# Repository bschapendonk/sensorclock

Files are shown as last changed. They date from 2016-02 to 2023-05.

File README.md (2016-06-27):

# sensorclock
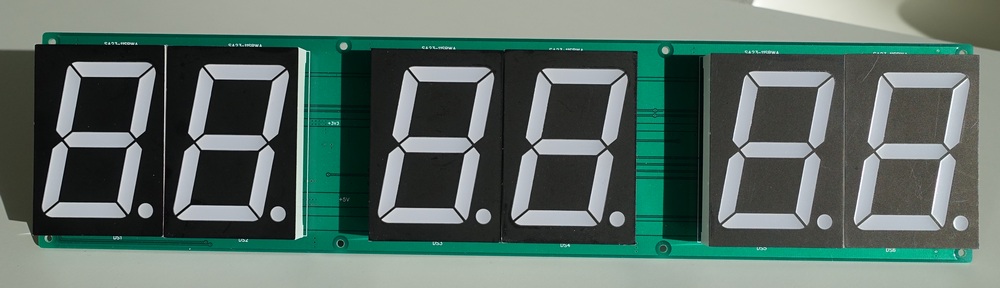
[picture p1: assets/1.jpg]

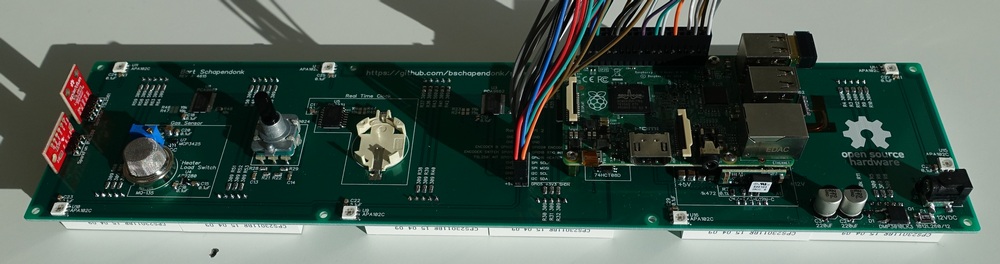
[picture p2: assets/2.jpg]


I'm a software engineer by trade and I was looking for a nice project to use [Windows 10 IoT Core](https://dev.windows.com/en-us/iot) running on a Raspberry Pi 2 Model B.
So I decided on an clock inspired by Steve Gardner's [6 Digit LED Clock](http://sdgelectronics.co.uk/ledclock-projects/) project.
Initially I only planned on the clock, but I ended up addeding a bunch of sensors that might be used for some "IoT" in the feature.

Everything is controlled thru I2C, except the RGB leds which use SPI, some GPIO's for the rotary encoder, interrupts from the sensors and control lines to turn off the +3V3 (to reset all I2C devices). Basically any MCU that has I2C, SPI and some GPIO's can be used.

*The new Raspberry Pi 3 is pin compatible and runs even better*

* [Schematic](/hardware/pdf/sensorclock.pdf)
* [Board Top](/hardware/pdf/sensorclock_top.pdf)
* [Board Bottom](/hardware/pdf/sensorclock_bottom.pdf)
* [Gerbers](/hardware/gerber)

## things learned / improvements / mistakes
* U2 has an invalid I2C address
 * [Workaround] Use ALLCALL to enable SUBADDR1 on all PCA9622's, then disable SUBADDR1 on the good addressed PCA9622's and use SUBADDR1 to address the wrong addressed U2
* The MCP3425 and DS3231 have the same I2C address #fail
 * [Workaround] For now I cut the SDA/SCL traces to the DS3231
* The interconnect between te sensorclock and the Raspberrry Pi 2
 * This is a custom cable which saved time in design process of the board (less complex routing), but in hindsight this was a mistake since the assembly of the cable is quite difficult and error prone.
 
## features
* Windows 10 IoT Core controlled
* Six 7-segment 70mm (2.3") high displays
* Eight APA102C serial controlled RGB led's for ambient lighting or mood indication
* Temperature, humidity, barometric pressure, ambient light and air quality sensors
* Mechanical rotary encoder with switch for user input

## components
* Raspberry Pi 2 Model B
* ~~DS3231 [http://datasheets.maximintegrated.com/en/ds/DS3231.pdf]~~ (address conflict)
* PEC16 [http://www.bourns.com/data/global/pdfs/pec16.pdf]
* APA102C [http://www.adafruit.com/datasheets/APA102.pdf]

### clock
* PCA9622 [http://www.nxp.com/documents/data_sheet/PCA9622.pdf]
* SA23-11SRWA [http://www.kingbrightusa.com/images/catalog/spec/SA23-11SRWA.pdf]

### sensors
* SparkFun Atmospheric Sensor Breakout - BME280 [https://www.sparkfun.com/products/13676]
* SparkFun Luminosity Sensor Breakout - TSL2561 [https://www.sparkfun.com/products/12055]
* MQ-135 air quality sensor, ADC and loadswitch
 * MCP3425 [http://ww1.microchip.com/downloads/en/DeviceDoc/22072b.pdf]
 * AP2280 [http://www.diodes.com/_files/datasheets/AP2280.pdf]

**!!This is a work in progress, use at your own risk!!**

## renders

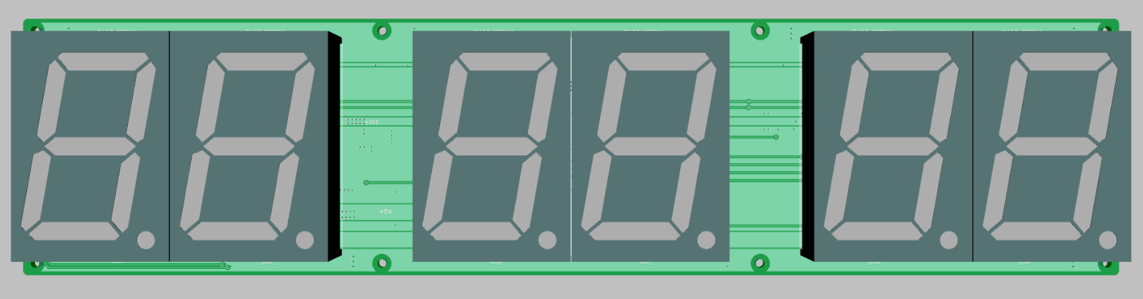
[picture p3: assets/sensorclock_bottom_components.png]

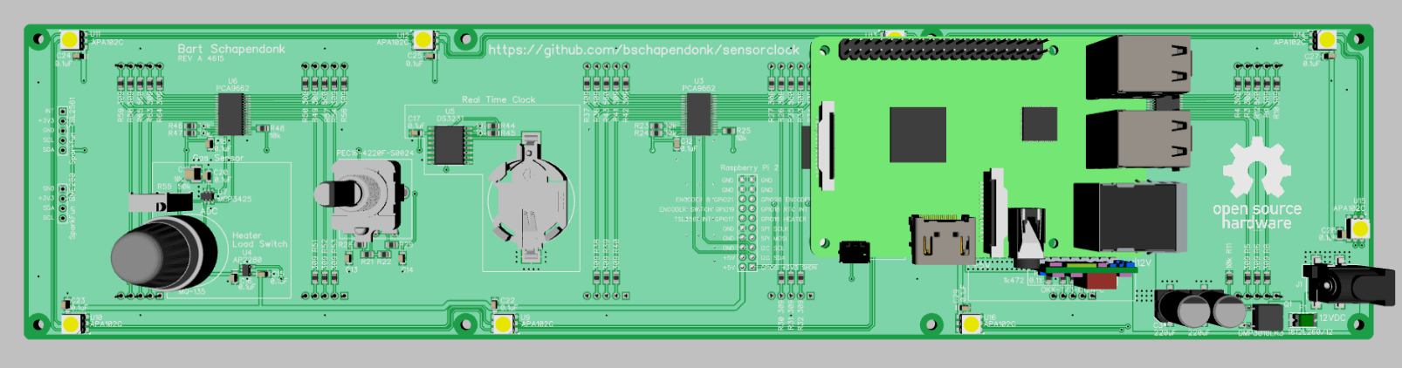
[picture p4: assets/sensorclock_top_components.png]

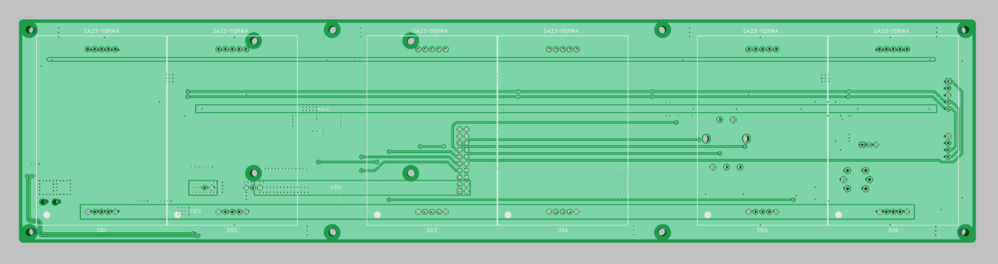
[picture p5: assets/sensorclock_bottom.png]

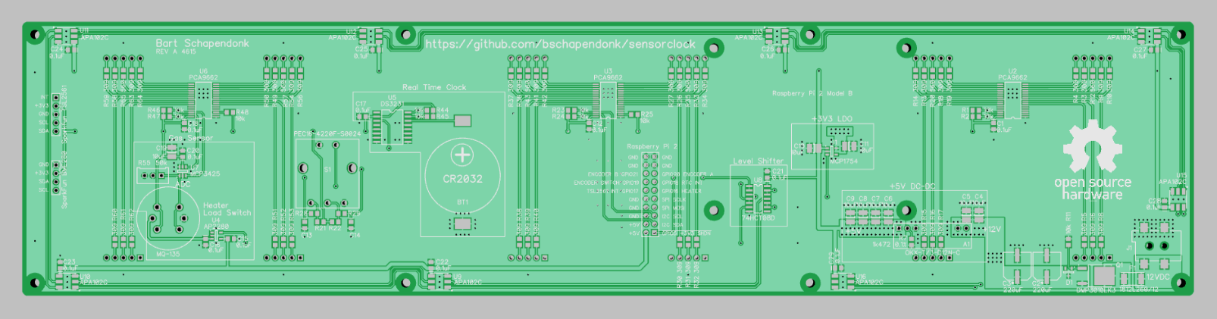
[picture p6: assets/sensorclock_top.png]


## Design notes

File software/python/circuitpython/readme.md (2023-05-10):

## CircuitPython Libraries
[CircuitPython Libraries
](https://circuitpython.org/libraries)

### Community Bundle
- adafruit_bme280/
- adafruit_bus_device/
- adafruit_register /
- asyncio/
- adafruit_datetime
- adafruit_ds3231
- adafruit_dotstar
- adafruit_ntp
- adafruit_ticks
- adafruit_tsl2561

### Community Bundle
- tzdb/

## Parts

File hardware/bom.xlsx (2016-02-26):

sensorclock_without_rtc_and_rotaryencoder
Mouser No | Mfr. # | Manufacturer | Desc. | RoHS | Lifecycle | Customer Part No. | Order Qty. | Price (EUR) | Ext: (EUR)
667-ERJ-6ENF1002V | ERJ-6ENF1002V | Panasonic | Thick Film Resistors - SMD 0805 10Kohms 1% Tol | RoHS Compliant By Exemption |  |  | 13 | € 0,024 | € 0,31
667-ERJ-6ENF3090V | ERJ-6ENF3090V | Panasonic | Thick Film Resistors - SMD 0805 309ohms 1% Tol | RoHS Compliant By Exemption |  |  | 42 | € 0,026 | € 1,09
667-ERJ-6ENF5600V | ERJ-6ENF5600V | Panasonic | Thick Film Resistors - SMD 0805 560ohms 1% Tol | RoHS Compliant By Exemption |  |  | 6 | € 0,091 | € 0,55
552-PSAC30U-120-R | PSAC30U-120-R | Phihong | Desktop AC Adapters 30W 12V 2.5A 3-WIRE INPUT ADAPTER | RoHS Compliant | End of Life |  | 1 | € 21,56 | € 21,56
771-74HCT08D-T | 74HCT08D,653 | NXP | Logic Gates QUAD 2-IN AND GATE | RoHS Compliant |  |  | 1 | € 0,398 | € 0,40
579-MCP3425A0T-E/CH | MCP3425A0T-E/CH | Microchip | Analog to Digital Converters - ADC 16-B delta-sigma ADC Sngl Ch 15sps | RoHS Compliant |  |  | 1 | € 2,15 | € 2,15
621-AP2280-1WG-7 | AP2280-1WG-7 | Diodes Incorporated | Power Switch ICs - Power Distribution Programmable Load Switch 1.5V - 6V | RoHS Compliant |  |  | 1 | € 0,585 | € 0,59
771-PCA9622DR,118 | PCA9622DR,118 | NXP | LED Lighting Drivers 16-BIT FM+ I2C-BUS 100mA 40V LED driver | RoHS Compliant |  |  | 3 | € 2,28 | € 6,84
579-MCP1754T3302EOT | MCP1754T-3302E/OT | Microchip | LDO Voltage Regulators LDO | RoHS Compliant |  |  | 1 | € 0,398 | € 0,40
652-3296W-1-503LF | 3296W-1-503LF | Bourns | Trimmer Resistors - Through Hole 3/8" 50Kohms Sealed Vertical Adjust | RoHS Compliant By Exemption |  |  | 1 | € 2,28 | € 2,28
667-ERA-6AEB1471V | ERA-6AEB1471V | Panasonic | Thin Film Resistors - SMD 0805 1.47Kohm 0.1% 25ppm | RoHS Compliant By Exemption |  |  | 1 | € 0,57 | € 0,57
621-DMP3010LK3-13 | DMP3010LK3-13 | Diodes Incorporated | MOSFET MOSFET BVDSS: 25V-30 V-30V TO252 T&R 2.5K | RoHS Compliant |  |  | 1 | € 0,604 | € 0,60
490-PJ-002AH-SMT-TR | PJ-002AH-SMT-TR | CUI Inc. | DC Power Connectors Power Jacks | RoHS Compliant | New At Mouser |  | 1 | € 1,56 | € 1,56
576-1812L260/12MR | 1812L260/12MR | Littelfuse | Resettable Fuses - PPTC PTC 12V POLY SURF MOUNT 1812 2.6A | RoHS Compliant |  |  | 1 | € 0,869 | € 0,87
604-SA23-11SRWA | SA23-11SRWA | Kingbright | LED Displays & Accessories SUPER RED DIFFUSED 1 DIGIT | RoHS Compliant |  |  | 6 | € 5,51 | € 33,06
863-MMBZ5250BLT1G | MMBZ5250BLT1G | ON Semiconductor | Zener Diodes 20V 225mW | RoHS Compliant |  |  | 1 | € 0,127 | € 0,13
81-GRM32DR71E106KA12 | GRM32DR71E106KA12L | Murata | Multilayer Ceramic Capacitors MLCC - SMD/SMT 1210 10uF 25volts X7R 10% | RoHS Compliant |  |  | 9 | € 0,661 | € 5,95
667-EEE-TG1E221UP | EEE-TG1E221UP | Panasonic | Aluminium Electrolytic Capacitors - SMD 220UF 25V ELECT TG SMD | RoHS Compliant |  |  | 2 | € 0,896 | € 1,79
81-GRM40X104K25L | GRM21BR71E104KA01L | Murata | Multilayer Ceramic Capacitors MLCC - SMD/SMT 0805 0.1uF 25volts X7R 10% | RoHS Compliant |  |  | 15 | € 0,068 | € 1,02
580-OKX-T/3-D12N-C | OKX-T/3-D12N-C | Murata | Non-Isolated DC/DC Converters 12Vin 0.75-5.5Vout 3A Neg logic SIP | RoHS Compliant |  |  | 1 | € 5,61 | € 5,61

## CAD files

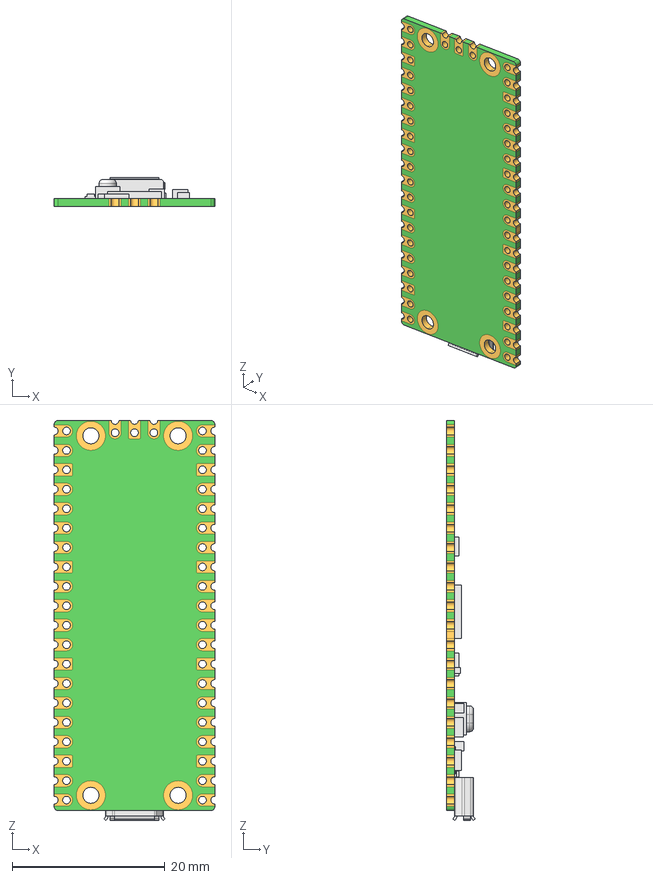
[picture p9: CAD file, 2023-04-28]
hardware/picow_adapter/3dmodels/Pico-R3-PICOPICO_assm_140121.step
21.0 x 3.73 x 52.3 mm
PICO_REF_BOARD.STEP
PICO_REF_USB.STEP
PICO_REF_USB.STEP001
PICO_REF_USB.STEP002
PICO_REF_USB.STEP003
PICO_REF_USB.STEP004
PICO_REF_SWITCH.STEP
PICO_REF_MICROCONTROLLER.STEP
PICO_REF_LED.STEP
PICO_REF_ONSEMI.STEP
PICO_BOURNS.STEP
PICO_MURATA.STEP x 2
PICO_RICHTEK.STEP
PICO_DIODES.STEP
PICO_AEL.STEP
PICO_WINBOND.STEP

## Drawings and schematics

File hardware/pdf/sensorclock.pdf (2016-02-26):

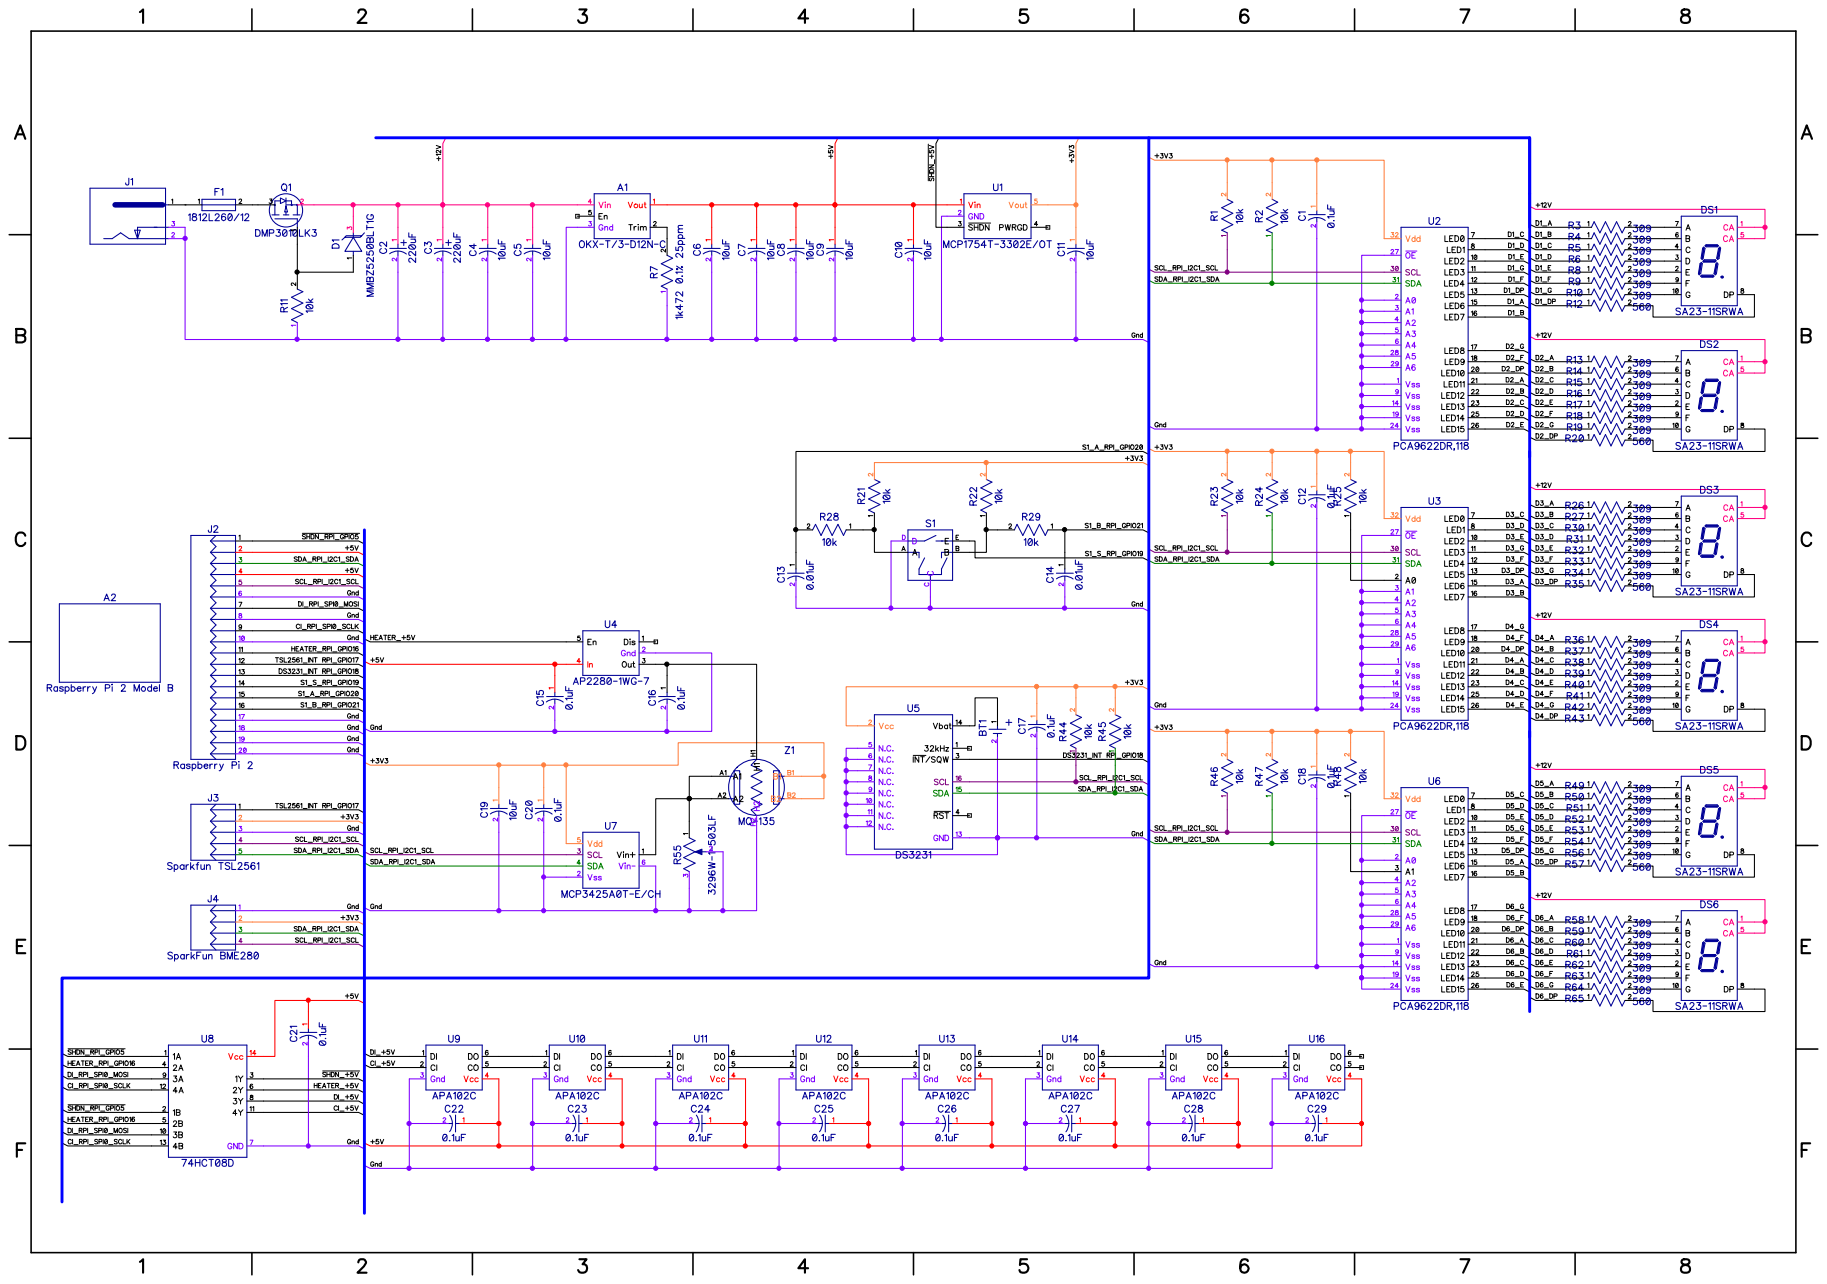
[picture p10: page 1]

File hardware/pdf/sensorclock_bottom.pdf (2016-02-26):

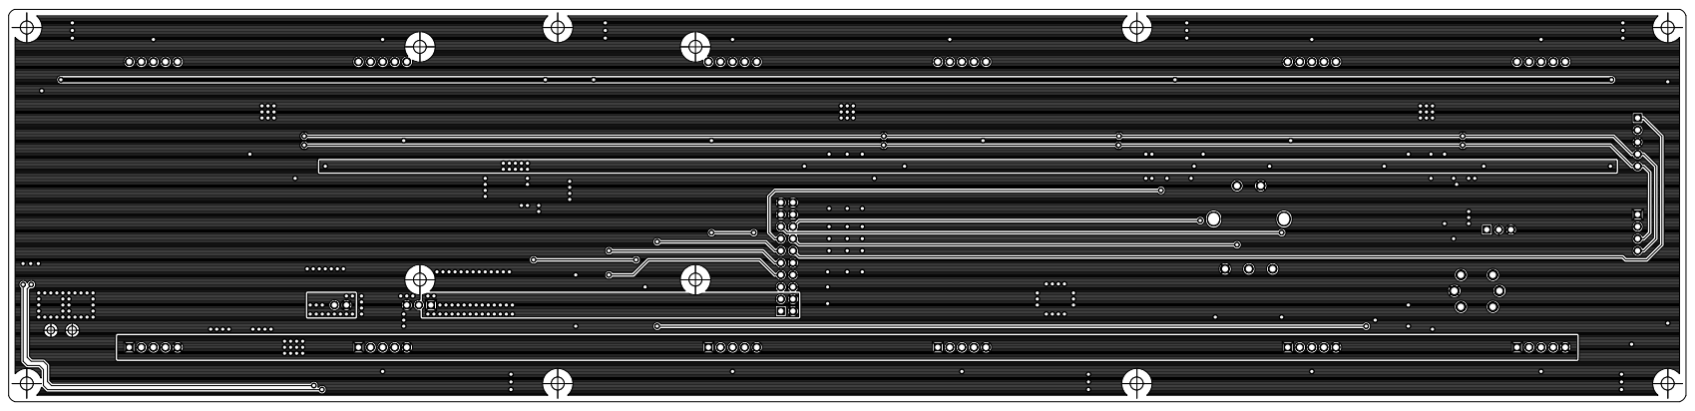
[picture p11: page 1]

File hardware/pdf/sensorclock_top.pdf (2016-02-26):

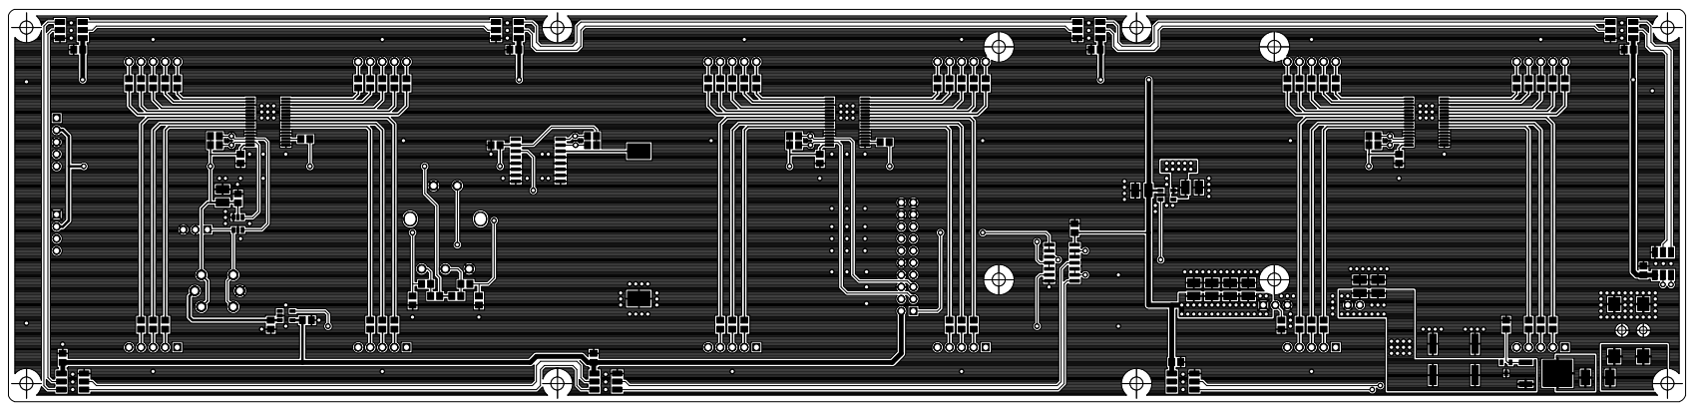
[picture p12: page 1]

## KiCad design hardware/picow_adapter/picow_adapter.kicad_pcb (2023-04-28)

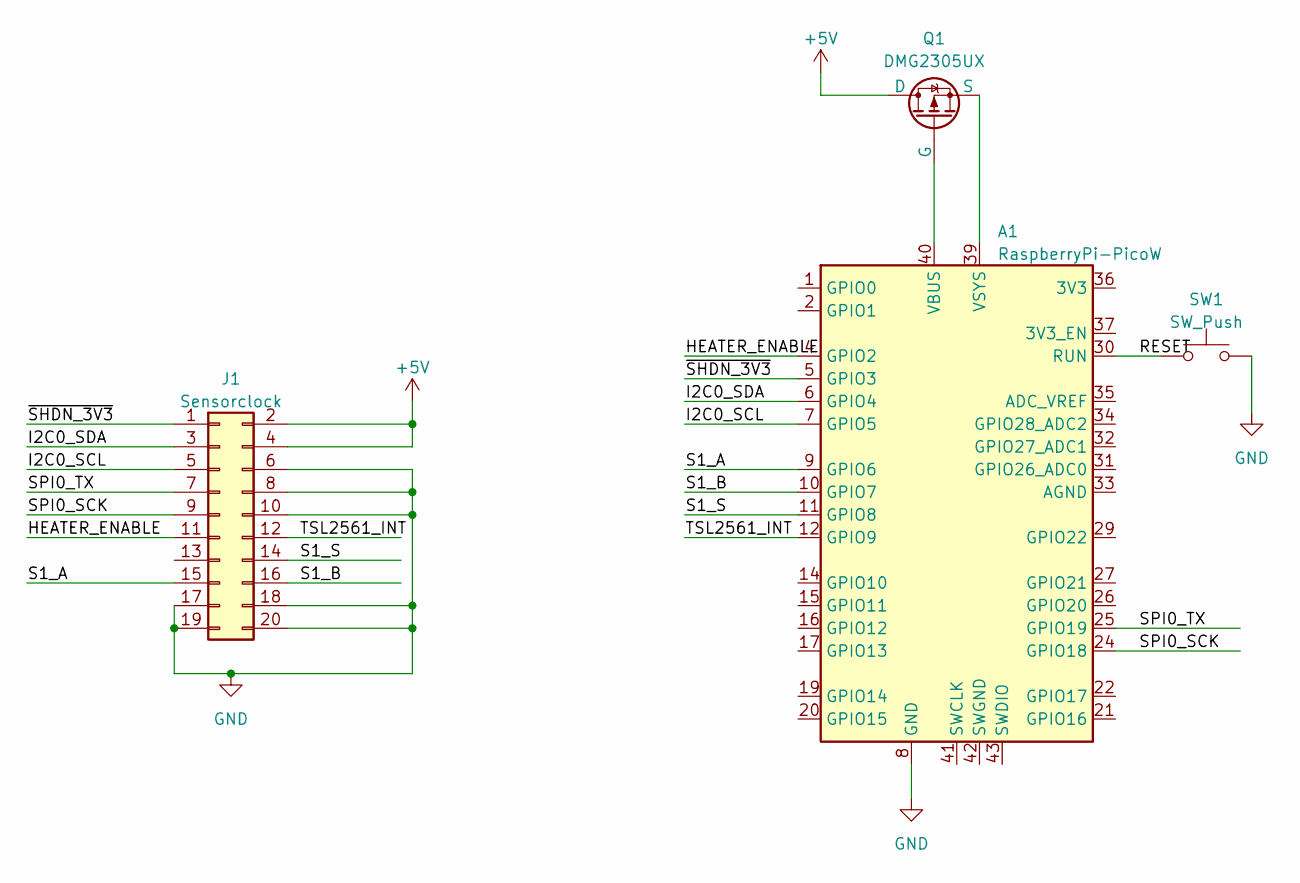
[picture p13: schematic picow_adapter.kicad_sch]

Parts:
A1: RaspberryPi-PicoW; Raspberry_Pi_Pico_SMT_THT
J1: Sensorclock; PinSocket_2x10_P2.54mm_Vertical
Q1: DMG2305UX; SOT-23
SW1: SW_Push; SW_SPST_B3U-1000P

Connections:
+5V: J1.2, J1.4, Q1.3 (D)
/HEATER_ENABLE: A1.4 (GPIO2), J1.11
/I2C0_SCL: A1.7 (GPIO5), J1.5
/I2C0_SDA: A1.6 (GPIO4), J1.3
/RESET: A1.30 (RUN), SW1.1
/S1_A: A1.9 (GPIO6), J1.15
/S1_B: A1.10 (GPIO7), J1.16
/S1_S: A1.11 (GPIO8), J1.14
/SPI0_SCK: A1.24 (GPIO18), J1.9
/SPI0_TX: A1.25 (GPIO19), J1.7
/TSL2561_INT: A1.12 (GPIO9), J1.12
/~SHDN_3V3: A1.5 (GPIO3), J1.1
GND: A1.3 (GND), A1.8 (GND), A1.13 (GND), A1.18 (GND), A1.23 (GND), A1.28 (GND), A1.38 (GND), J1.6, J1.8, J1.10, J1.17, J1.18, J1.19, J1.20, SW1.2
unnamed: A1.40 (VBUS), Q1.1 (G)
unnamed: A1.39 (VSYS), Q1.2 (S)

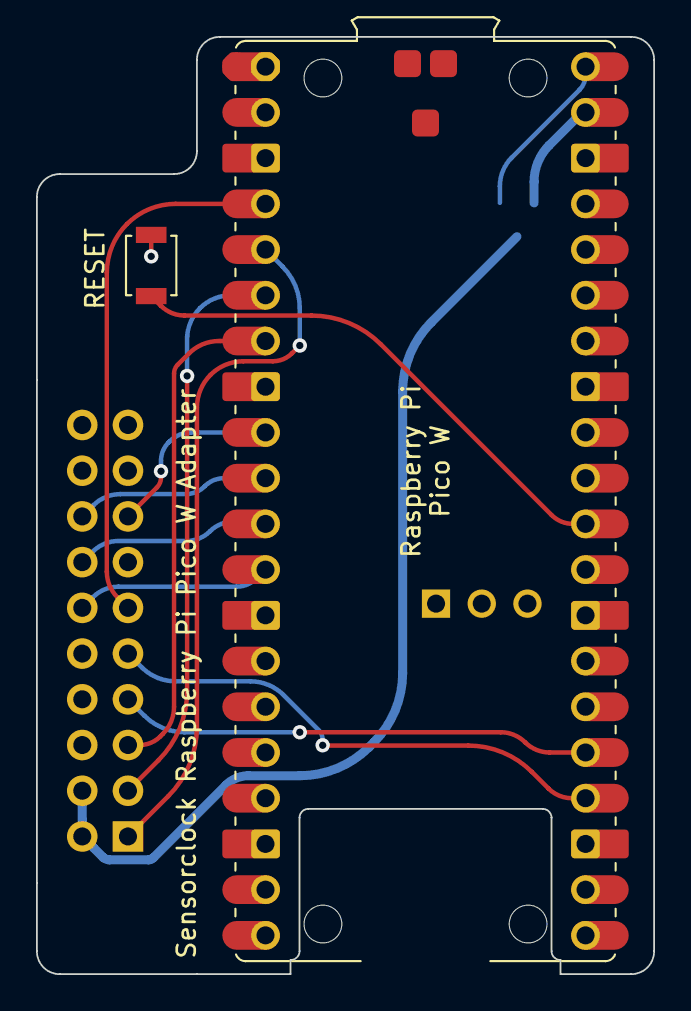
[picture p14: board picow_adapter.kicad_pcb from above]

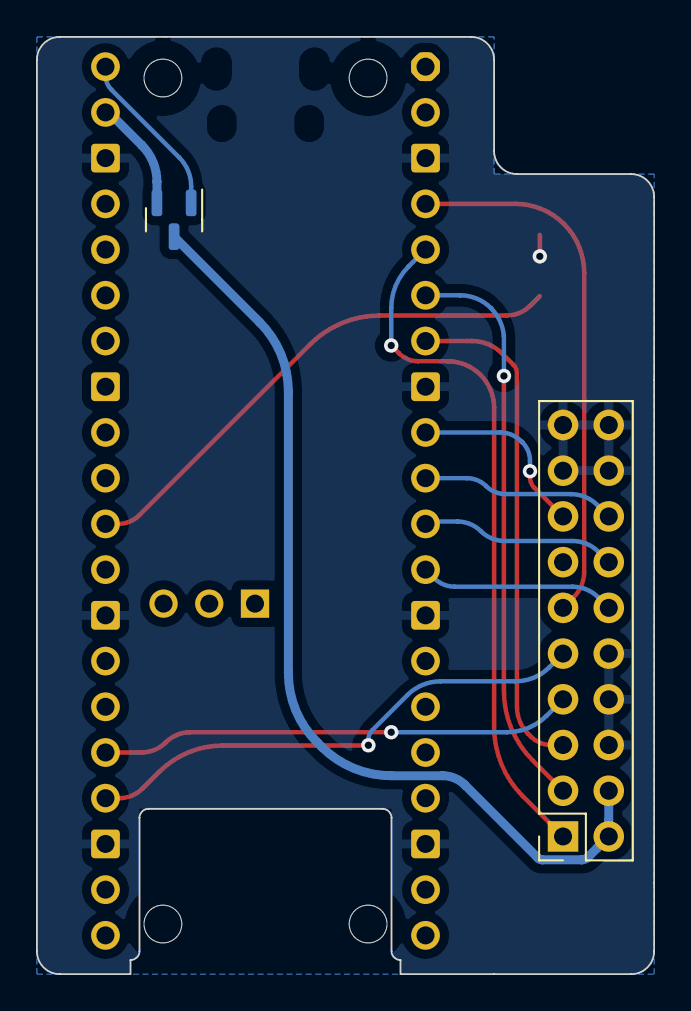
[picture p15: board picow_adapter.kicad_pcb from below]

Board: 2 copper layers, 34.3 x 52.1 mm, 4 parts (2 on the bottom side), 15 nets.

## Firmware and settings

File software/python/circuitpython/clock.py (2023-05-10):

import busio
import time


class Clock:
    def __init__(self, i2c_bus: busio.I2C):
        self.i2c = i2c_bus
        self.display_dot = False
        self.ADDR_ALLCALL = 0x70
        self.ADDR_HOUR = 0x71
        self.ADDR_MINUTE = 0x01
        self.ADDR_SECOND = 0x02
        self.AUTO_INCREMENT = 0x80
        self.DIMM_HOUR_BEGIN = 22
        self.DIMM_HOUR_END = 8
        self.MODE1_ALLCALL = 0x01
        self.MODE1_SLEEP = 0x10
        self.MODE1_SUBADDR1 = 0x08
        self.PWM_DEFAULT = 0x44
        self.PWM_DIMM = 0x01
        self.REGISTER_GRPPWM = 0x12
        self.REGISTER_LEDOUT0 = 0x14
        self.REGISTER_MODE1 = 0x00
        self.REGISTER_PWM0 = 0x02
        self.second = 0
        self.minute = 0
        self.hour = 0
        self.DIGITS = [
            [
                self.REGISTER_PWM0 | self.AUTO_INCREMENT,
                0xFF,
                0xFF,
                0xFF,
                0x00,
                0xFF,
                0x00,
                0xFF,
                0xFF,
                0x00,
                0xFF,
                0x00,
                0xFF,
                0xFF,
                0xFF,
                0xFF,
                0xFF,
            ],
            [
                self.REGISTER_PWM0 | self.AUTO_INCREMENT,
                0xFF,
                0xFF,
                0xFF,
                0x00,
                0xFF,
                0x00,
                0xFF,
                0xFF,
                0x00,
                0x00,
                0x00,
                0x00,
                0xFF,
                0xFF,
                0x00,
                0x00,
            ],
            [
                self.REGISTER_PWM0 | self.AUTO_INCREMENT,
                0xFF,
                0xFF,
                0xFF,
                0x00,
                0xFF,
                0x00,
                0xFF,
                0xFF,
                0xFF,
                0x00,
                0x00,
                0xFF,
                0xFF,
                0x00,
                0xFF,
                0xFF,
            ],
            [
                self.REGISTER_PWM0 | self.AUTO_INCREMENT,
                0xFF,
                0xFF,
                0xFF,
                0x00,
                0xFF,
                0x00,
                0xFF,
                0xFF,
                0xFF,
                0x00,
                0x00,
                0xFF,
                0xFF,
                0xFF,
                0xFF,
                0x00,
            ],
            [
                self.REGISTER_PWM0 | self.AUTO_INCREMENT,
                0xFF,
                0xFF,
                0xFF,
                0x00,
                0xFF,
                0x00,
                0xFF,
                0xFF,
                0xFF,
                0xFF,
                0x00,
                0x00,
                0xFF,
                0xFF,
                0x00,
                0x00,
            ],
            [
                self.REGISTER_PWM0 | self.AUTO_INCREMENT,
                0xFF,
                0xFF,
                0xFF,
                0x00,
                0xFF,
                0x00,
                0xFF,
                0xFF,
                0xFF,
                0xFF,
                0x00,
                0xFF,
                0x00,
                0xFF,
                0xFF,
                0x00,
            ],
            [
                self.REGISTER_PWM0 | self.AUTO_INCREMENT,
                0xFF,
                0xFF,
                0xFF,
                0x00,
                0xFF,
                0x00,
                0xFF,
                0xFF,
                0xFF,
                0xFF,
                0x00,
                0xFF,
                0x00,
                0xFF,
                0xFF,
                0xFF,
            ],
            [
                self.REGISTER_PWM0 | self.AUTO_INCREMENT,
                0xFF,
                0xFF,
                0xFF,
                0x00,
                0xFF,
                0x00,
                0xFF,
                0xFF,
                0x00,
                0x00,
                0x00,
                0xFF,
                0xFF,
                0xFF,
                0x00,
                0x00,
            ],
            [
                self.REGISTER_PWM0 | self.AUTO_INCREMENT,
                0xFF,
                0xFF,
                0xFF,
                0x00,
                0xFF,
                0x00,
                0xFF,
                0xFF,
                0xFF,
                0xFF,
                0x00,
                0xFF,
                0xFF,
                0xFF,
                0xFF,
                0xFF,
            ],
            [
                self.REGISTER_PWM0 | self.AUTO_INCREMENT,
                0xFF,
                0xFF,
                0xFF,
                0x00,
                0xFF,
                0x00,
                0xFF,
                0xFF,
                0xFF,
                0xFF,
                0x00,
                0xFF,
                0xFF,
                0xFF,
                0xFF,
                0x00,
            ],
            [
                self.REGISTER_PWM0 | self.AUTO_INCREMENT,
                0xFF,
                0x00,
                0x00,
                0x00,
                0x00,
                0x00,
                0x00,
                0xFF,
                0x00,
                0xFF,
                0x00,
                0xFF,
                0xFF,
                0xFF,
                0xFF,
                0xFF,
            ],
            [
                self.REGISTER_PWM0 | self.AUTO_INCREMENT,
                0xFF,
                0x00,
                0x00,
                0x00,
                0x00,
                0x00,
                0x00,
                0xFF,
                0x00,
                0x00,
                0x00,
                0x00,
                0xFF,
                0xFF,
                0x00,
                0x00,
            ],
            [
                self.REGISTER_PWM0 | self.AUTO_INCREMENT,
                0xFF,
                0x00,
                0x00,
                0x00,
                0x00,
                0x00,
                0x00,
                0xFF,
                0xFF,
                0x00,
                0x00,
                0xFF,
                0xFF,
                0x00,
                0xFF,
                0xFF,
            ],
            [
                self.REGISTER_PWM0 | self.AUTO_INCREMENT,
                0xFF,
                0x00,
                0x00,
                0x00,
                0x00,
                0x00,
                0x00,
                0xFF,
                0xFF,
                0x00,
                0x00,
                0xFF,
                0xFF,
                0xFF,
                0xFF,
                0x00,
            ],
            [
                self.REGISTER_PWM0 | self.AUTO_INCREMENT,
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

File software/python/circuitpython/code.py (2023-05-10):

import adafruit_ds3231
import adafruit_dotstar
import adafruit_ntp
import asyncio
import board
import busio
import clock
import digitalio
import mdns
import os
import socketpool
import time
import wifi

from adafruit_datetime import datetime
from tzdb import timezone


# try to update the rtc every 5 minutes from ntp
async def update_rtc():
    while True:
        try:
            utc_now = datetime.fromtimestamp(time.mktime(ntp.datetime))
            rtc.datetime = timezone(tz_name).fromutc(utc_now).timetuple()
        except OSError as error:
            print(error)
            continue

        await asyncio.sleep(300)


async def update_clock():
    while True:
        clock.tick(rtc.datetime)
        await asyncio.sleep(0.02)


async def main():
    update_rtc_task = asyncio.create_task(update_rtc())
    update_clock_task = asyncio.create_task(update_clock())
    await asyncio.gather(update_rtc_task, update_clock_task)


# initialize and turn off all apa102 leds
pixels = adafruit_dotstar.DotStar(board.GP18, board.GP19, 8, brightness=0)
for pixel in range(len(pixels)):
    pixels[pixel] = (0, 0, 0)

# turn of the heater for the gas sensors
heater = digitalio.DigitalInOut(board.GP2)
heater.direction = digitalio.Direction.OUTPUT
heater.value = False

# enable 3v3
shdn_3v3 = digitalio.DigitalInOut(board.GP3)
shdn_3v3.direction = digitalio.Direction.OUTPUT
shdn_3v3.value = False
time.sleep(0.1)
shdn_3v3.value = True

wifi.radio.connect(os.getenv("WIFI_SSID"), os.getenv("WIFI_PASSWORD"))
print("Connected to WiFi")

mdns_server = mdns.Server(wifi.radio)
mdns_server.hostname = "custom-mdns-hostname"
mdns_server.advertise_service(service_type="_http", protocol="_tcp", port=80)

pool = socketpool.SocketPool(wifi.radio)
print("My IP address is", wifi.radio.ipv4_address)

ntp = adafruit_ntp.NTP(pool, server=os.getenv("NTP_SERVER"), tz_offset=0)

i2c = busio.I2C(scl=board.GP5, sda=board.GP4, frequency=400_000)
rtc = adafruit_ds3231.DS3231(i2c)
tz_name = os.getenv("TZ_NAME")

clock = clock.Clock(i2c)

asyncio.run(main())

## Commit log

2022-09-22 .NET 7 rc1
    [config.txt]
2022-11-16 Raspberry Pi 4B get! Hello World ARM64!
2025-03-19 Update Microsoft.Extensions.Hosting.Systemd package version
    Updated the version of the `Microsoft.Extensions.Hosting.Systemd` package in the `Directory.Packages.props` file from `10.0.0-preview.1.25080.5` to `10.0.0-preview.2.25163.2`.
2025-04-13 Update Microsoft.Extensions.Hosting.Systemd package version
    Updated the version of the `Microsoft.Extensions.Hosting.Systemd` package from `10.0.0-preview.2.25163.2` to `10.0.0-preview.3.25171.5` in the `Directory.Packages.props` file.
2025-05-13 Update Microsoft.Extensions.Hosting.Systemd package version
    Updated the version of the `Microsoft.Extensions.Hosting.Systemd` package in the `Directory.Packages.props` file from `10.0.0-preview.3.25171.5` to `10.0.0-preview.4.25258.110`.
2025-05-14 Revert Microsoft.Extensions.Hosting.Systemd package version to 9.0.5 and update target framework to net9.0
2025-06-13 Update package versions in Directory.Packages.props
    Updated `Iot.Device.Bindings` to version `4.0.1` and
    `Microsoft.Extensions.Hosting.Systemd` to version `9.0.6`.
2025-07-31 Update Microsoft.Extensions.Hosting.Systemd to 9.0.7
    Updated the version of the package `Microsoft.Extensions.Hosting.Systemd` from `9.0.6` to `9.0.7` in the `Directory.Packages.props` file.
2025-09-02 Update Microsoft.Extensions.Hosting.Systemd to 9.0.8
    Updated the version of the package `Microsoft.Extensions.Hosting.Systemd` from `9.0.7` to `9.0.8` in the `Directory.Packages.props` file.
2025-09-12 Update Microsoft.Extensions.Hosting.Systemd to 9.0.9
    Updated the version of the package `Microsoft.Extensions.Hosting.Systemd` from `9.0.8` to `9.0.9` in the `Directory.Packages.props` file.
2025-10-20 Update Microsoft.Extensions.Hosting.Systemd to 9.0.10
    Updated the `Directory.Packages.props` file to increment the
    version of the `Microsoft.Extensions.Hosting.Systemd` package
    from `9.0.9` to `9.0.10`. This ensures the project benefits
    from any bug fixes, performance improvements, or new features
    introduced in the updated version. No other package versions
    were modified.
2025-11-12 Update Microsoft.Extensions.Hosting.Systemd to version 10.0.0 and change target framework to net10.0
2025-12-09 Update Microsoft.Extensions.Hosting.Systemd to 10.0.1
    Updated the `Microsoft.Extensions.Hosting.Systemd` package version in the `Directory.Packages.props` file from `10.0.0` to `10.0.1`. This minor version update likely includes bug fixes or small improvements.
2026-03-18 #
    Update NuGet package versions for Iot and Systemd
    Upgraded Iot.Device.Bindings from 4.0.1 to 4.1.0 and Microsoft.Extensions.Hosting.Systemd from 10.0.1 to 10.0.5 to include the latest features and fixes.
2026-04-01 Update Iot.Device.Bindings to version 4.2.0
    Upgraded the Iot.Device.Bindings NuGet package from version 4.1.0 to 4.2.0 in Directory.Packages.props to incorporate the latest features and fixes. No other dependencies were changed.
2026-04-15 Update Systemd package to version 10.0.6
    Upgraded Microsoft.Extensions.Hosting.Systemd from 10.0.5 to 10.0.6 in Directory.Packages.props to ensure the latest fixes and improvements are included. No other dependencies were changed.
2026-05-26 Update Systemd package to version 10.0.8
    Upgraded Microsoft.Extensions.Hosting.Systemd NuGet package from version 10.0.6 to 10.0.8 in Directory.Packages.props to ensure compatibility and receive the latest fixes and improvements.
2026-06-26 Update CI actions and Systemd package version
    Upgraded actions/checkout and actions/upload-artifact to v7 in main.yml. Bumped Microsoft.Extensions.Hosting.Systemd to 10.0.9 in Directory.Packages.props.
2026-07-21 Bump Systemd package to 10.0.10
    Updated Microsoft.Extensions.Hosting.Systemd NuGet package from version 10.0.9 to 10.0.10 in Directory.Packages.props to ensure latest fixes and improvements.
2026-07-31 Update .NET target framework to net11.0 and bump Systemd package version to 11.0.0-preview.6.26359.118
2026-07-31 Update CI workflow to use ubuntu-26.04-arm for build environment
2026-08-12 Bump Microsoft.Extensions.Hosting.Systemd to preview.7
    Updated Microsoft.Extensions.Hosting.Systemd package from 11.0.0-preview.6.26359.118 to 11.0.0-preview.7.26381.103 in Directory.Packages.props.
2026-09-09 Update Systemd package to 11.0.0-rc.1.26425.128
    Updated Microsoft.Extensions.Hosting.Systemd NuGet package from 11.0.0-preview.7.26381.103 to 11.0.0-rc.1.26425.128 in Directory.Packages.props.
